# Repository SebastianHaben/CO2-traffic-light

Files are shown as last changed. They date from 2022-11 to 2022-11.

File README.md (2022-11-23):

## CO2 Traffic Light
The CO2 traffic light can help you to know when it is time to let some fresh air into your room and is also capable of logging your data online. The integrated CO2 & VOC (Volatile Organic Compounds) sensor tracks the air quality and indicates via an LED status light if the room air quality is good (green), ok(yellow) or bad (red) as well as display the values, as well as the room temperature on an e-Paper display.

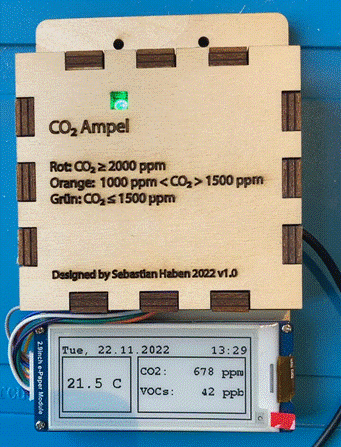
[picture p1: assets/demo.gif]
GIF of working project
  
  
### Contents
- Features
- Required parts
- Circuit & breadboard diagram
- Code and how to create a Firebase account
- Setting the correct timezone
- First start-up
- Laser cut housing
---
### Features
-	Measuring of temperature, eCO2 and VOC concentration in room air
-	Display of data as well as time and date (incl. correct time zone and daylight-saving time) on an e-Paper display.
-	Upload Data to a Google Firebase Realtime Database for analysis of historic trends
---
### Required parts
-	Wemos LOLIN D1 mini
-	Adafruit CSS811 air quality sensor
-	Adafruit MPL3115A2 Barometric Pressure Sensor
-	Waveshare 2.9 in E-Ink (E-Paper) display (black and white). Important: While other displays  sizes are also possible a lot of code rework (especially for graphics) will be necessary, for which no guide will be provided!
-	Adafruit Neopixel (or other WS2812B based  LED) or APA106 LED
-	Perf-board (I used a 40 x 60 mm one)

For Prototyping:
-	Large Breadboard
-	Dupont Jumper cables

For Housing:
-	6mm MDF plate
-	Screws (M2x8mm for Display and 2x10 mm for rest)
-	Hot glue or screws
---
### Circuit & Breadboard Diagram

The connections are done according to the breadboard view. In addition, a small table for each component is provided for each component with the corresponding pin on the D1 mini. 

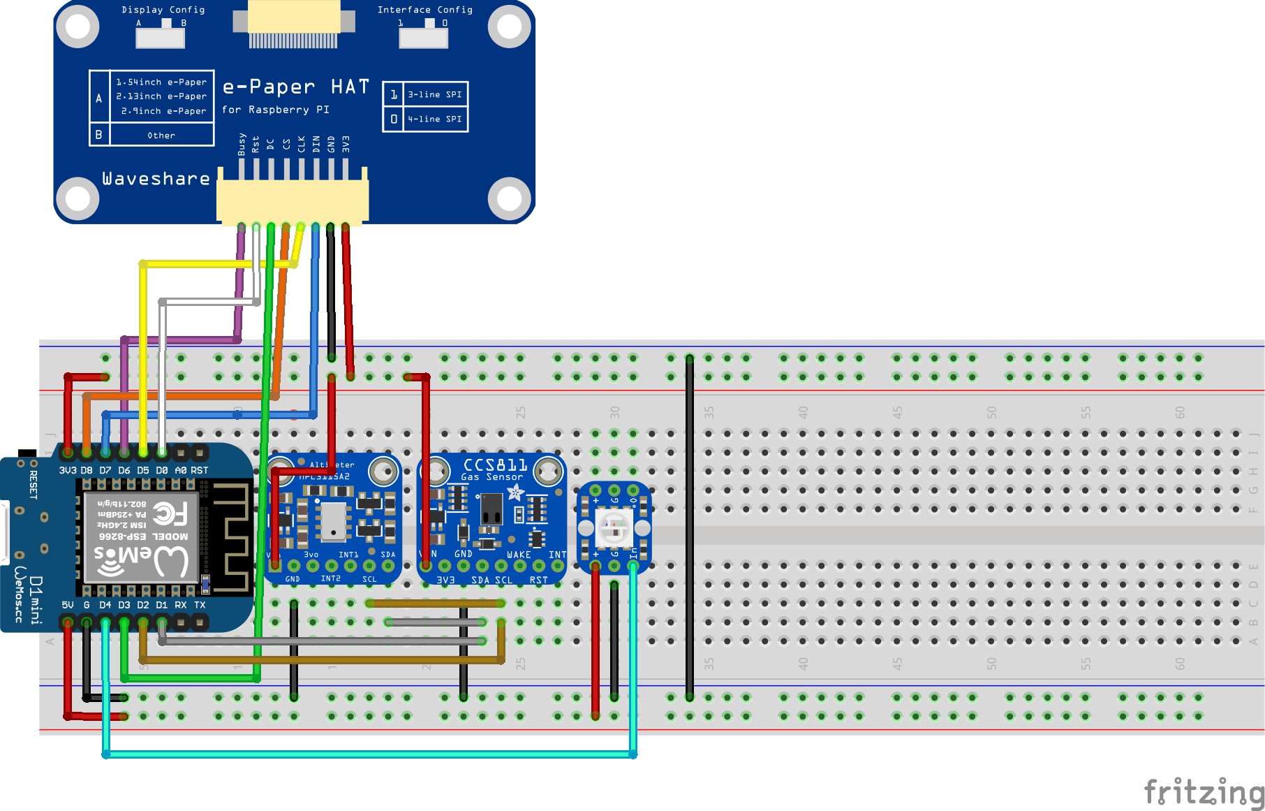
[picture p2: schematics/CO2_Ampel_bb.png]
Breadboard based hook-up diagram of project
  

__CSS811 & MPL3115A2__
|Pin on CSS811/MPL3115A2|Pin on D1 mini|
|:---:|:---:|
|VIN|3.3 V|
|GND|GND|
|SDA|D1|
|SCL|D2|

__Waveshare E-Ink Display__
|Pin on Waveshare|E-Ink Display	Pin on D1 mini|
|:---:|:---:|
|VCC|3.3 V|
|GND|GND|
|DIN|D7|
|CLK|D5|
|CS|D8|
|DC|D3|
|RST|D0|
|BUSY|D6|

__Neopixel__
|Pin on Neopixel|Pin on D1 mini|
|:---:|:---:|
|VIN|5V|
|GND|GND|
|DIN|D4|
---
### Code set-up and how to create a Firebase account
To run the project several things, need to be changed before flashing the code to the D1 mini. To save our data in the Google Firebase Realtime Database we first need to create a project in Google Firebase, create a new Realtime Database, grab the API-Key of the project and the database-URL as well as create the authentication via an e-mail address/ pass word combination. This handy tutorial will help you through each step of [setting up everything on Firebase.](https://randomnerdtutorials.com/esp8266-data-logging-firebase-realtime-database/)
After you have gathered all the required information you need to update the firebase-credentials.h file.

---
### Setting the correct time zone
To have the correct date and time displayed we need to set the correct time zone. This is done in line 84. To choose your correct time zone find your region and city in [this table](https://github.com/nayarsystems/posix_tz_db/blob/master/zones.csv) and replace the String with the corresponding string for your location.

---

### First start-up
After you have adjusted the code and the credentials you can flash it on the D1 mini. The final step is to connect the D1 mini to your WiFi. For this connect with your smartphone or tablet to the network “AutoConnectAP” and on the resulting page (if not forwarded automatically type 192.168.4.1 into your browser) find your WiFi’s SSID from the list and enter your password. The D1 mini should restart automatically and will connect to the WiFi. The credentials are stored on the D1 mini and are still available after a loss of power.

---

### Laser-cut Housing
I built this enclosure from 6mm birch MDF which might be also the new home for your own CO2 traffic light. I personally don’t own a laser cutter but online you can find shops that will cut the pieces for you at competitive rates. To place the project into the housing I soldered the sensors and the D1 mini onto a small perfboard.

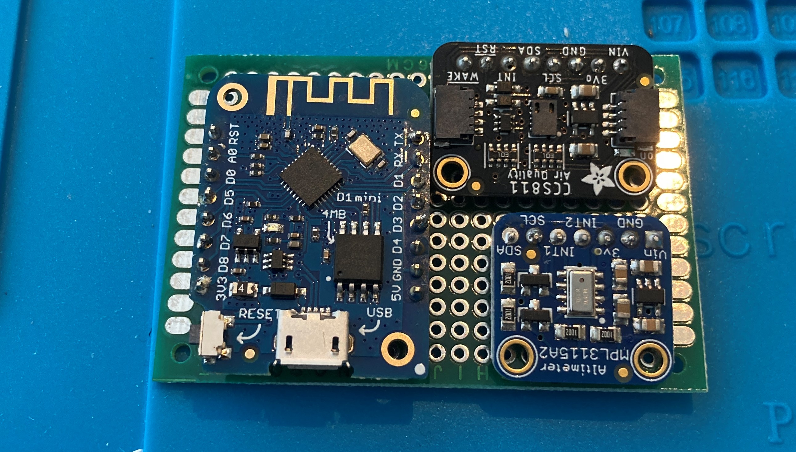
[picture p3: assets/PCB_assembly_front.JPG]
Front view PCB assembly
  
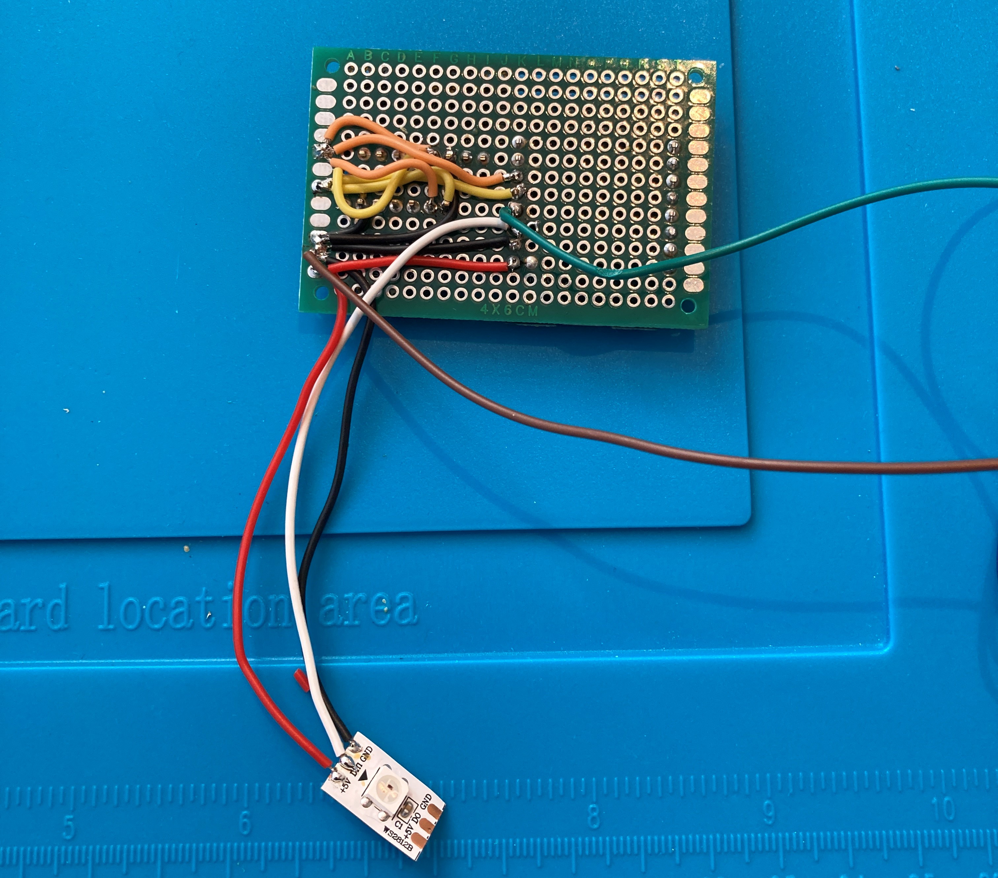
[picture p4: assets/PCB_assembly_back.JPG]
Back view PCB assembly
  
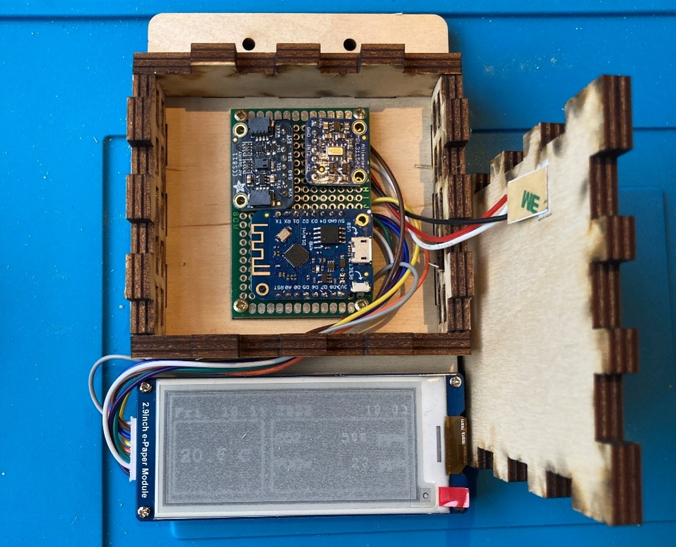
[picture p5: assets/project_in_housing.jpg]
Project in Housing


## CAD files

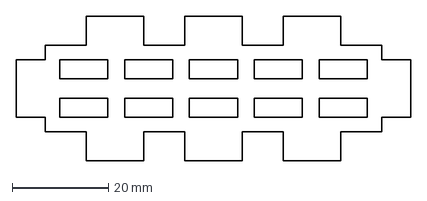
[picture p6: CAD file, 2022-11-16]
lasercutter housing/side.dxf
82.0 x 30.0 mm

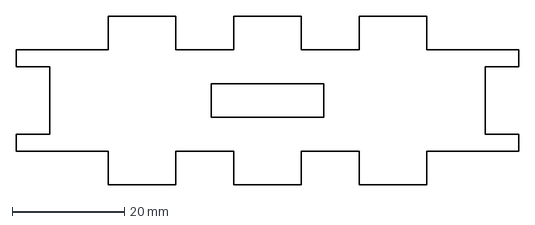
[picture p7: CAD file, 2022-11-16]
lasercutter housing/bottom.dxf
89.5 x 30.0 mm

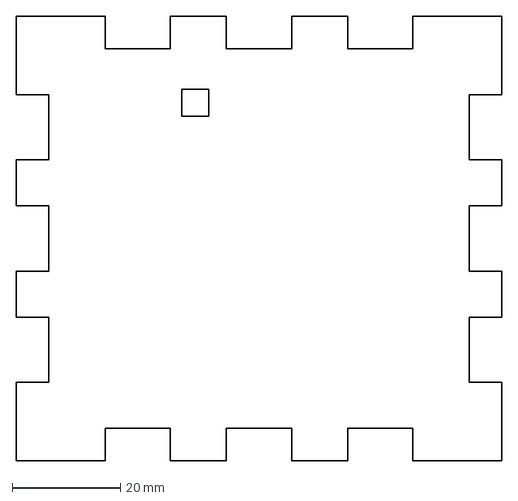
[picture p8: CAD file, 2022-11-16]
lasercutter housing/front.dxf
89.5 x 82.0 mm

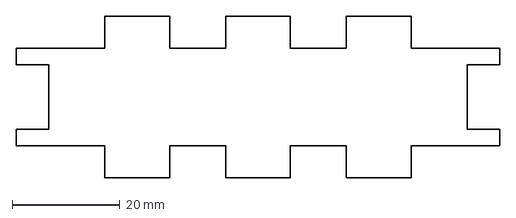
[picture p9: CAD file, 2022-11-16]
lasercutter housing/top.dxf
89.5 x 30.0 mm

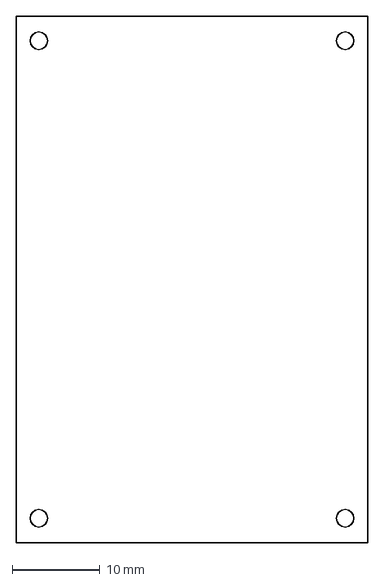
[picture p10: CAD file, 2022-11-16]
lasercutter housing/back_engra.dxf
40.0 x 60.0 mm

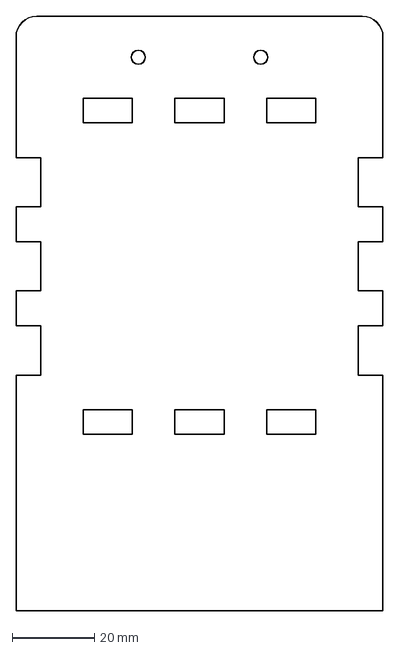
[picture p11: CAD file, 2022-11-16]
lasercutter housing/back.dxf
89.5 x 145.0 mm

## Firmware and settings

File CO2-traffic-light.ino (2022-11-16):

#include "time.h"
#include <Adafruit_NeoPixel.h>
#include <Wire.h>
#include <WiFiManager.h>
#include <Firebase_ESP_Client.h>
#include "addons/TokenHelper.h"
#include "addons/RTDBHelper.h"
#include <GxEPD2_BW.h>
#include "GxEPD2_display_selection_new_style.h"
#include <Fonts/FreeMonoBold9pt7b.h>
#include <Fonts/FreeMonoBold12pt7b.h>
#include "ccs811.h"
#include <Adafruit_MPL3115A2.h>
#include "firebase_credentials.h"

// Display information
#define SCREEN_WIDTH   296
#define SCREEN_HEIGHT  128
#define ENABLE_GxEPD2_GFX 0
// Static text on display
const char CO2[] = "CO2:";
const char VOCs[] = "VOCs:";

// Neopixel Information
#define NEOPIN  D4
#define NUMPIXELS 1

// DateTime information
struct tm lt;         
struct tm utc;
const char* ntpServer = "europe.pool.ntp.org";
struct tm timeinfo;

// Timer variables (send new readings every three minutes)
unsigned long sendDataPrevMillis = 0;
unsigned long timerDelay = 180000;

// Necessary for Firebase authentication
FirebaseData fbdo;
FirebaseAuth auth;
FirebaseConfig config;
FirebaseJson json;
String parentPath;
String uid;
String databasePath;
String tempPath = "/temperature";
String co2Path = "/eCO2";
String vocPath = "/VOC";
String timePath = "/timestamp";
String timeStamp;

// Initialize Neopixel & Sensors
Adafruit_NeoPixel pixels(NUMPIXELS, NEOPIN, NEO_GRB + NEO_KHZ800);
CCS811 ccs811(D3);
Adafruit_MPL3115A2 baro;

void setup() {
  Serial.begin(19200);
  // Use WifiManager to setup WiFi without providing password
  WiFiManager wm;
  bool res;
  res = wm.autoConnect("AutoConnectAP"); // password protected ap

    if(!res) {
        Serial.println("Failed to connect");
        // ESP.restart();
    } 
    else {
        //if you get here you have connected to the WiFi    
        Serial.println("connected...yeey :)");
    }
  // Start 
  Wire.begin(); 
  ccs811.set_i2cdelay(50); // Needed for ESP8266 because it doesn't handle I2C clock stretch correctly
  bool ok= ccs811.begin();
  if( !ok ) Serial.println("setup: CCS811 begin FAILED");
  ok= ccs811.start(CCS811_MODE_1SEC);
  if( !ok ) Serial.println("setup: CCS811 start FAILED");
  if (!baro.begin()) {
    Serial.println("Could not find sensor. Check wiring.");
    while(1);
  }
  // Get config time based on NTP server
  configTime("CET-1CEST,M3.5.0,M10.5.0/3", ntpServer);
  // Setup Display
  display.init();
  display_setup();
  display.hibernate();
  // Start-up Neopixel
  pixels.begin();
  pixels.setPixelColor(0, pixels.Color(32, 32, 32));
  // Connect to Firebase
  config.api_key = API_KEY;
  auth.user.email = USER_EMAIL;
  auth.user.password = USER_PASSWORD;
  config.database_url = DATABASE_URL;
  Firebase.reconnectWiFi(true);
  fbdo.setResponseSize(4096);
  // Feedback for token
  config.token_status_callback = FirestoreTokenStatusCallback;
  config.max_token_generation_retry = 5;
  // Initialize the library with the Firebase authen and config
  Firebase.begin(&config, &auth);
  // Getting the user UID might take a few seconds
  Serial.println("Getting User UID");
  while ((auth.token.uid) == "") {
    Serial.print('.');
    delay(1000);
  }
  uid = auth.token.uid.c_str();
  Serial.print("User UID: ");
  Serial.println(uid);
  // Update database path
  databasePath = "/UsersData/" + uid + "/CO2Ampel/readings";
}

void loop() {
  // Initiallize variables for readings
  uint16_t eco2, etvoc, errstat, raw;
  float temperature;
  
  // Get temperature
  temperature = baro.getTemperature();
  // Parse temperature & humidity to ccs811. Standrad value of 40% relative humidity is used due to lack of humidity sensor. 
  ccs811.set_envdata_Celsius_percRH(temperature, 40.0);
  ccs811.read(&eco2,&etvoc,&errstat,&raw);
  // Set color of Neopixel based on current CO2 value.
  if (eco2 <= 1000){
        pixels.setPixelColor(0, pixels.Color(0, 20, 0));
        }
      else if (eco2 > 1000 && eco2 <= 2000){
        pixels.setPixelColor(0, pixels.Color(10, 10, 0));
        }
      else{
        pixels.setPixelColor(0, pixels.Color(20, 0, 0));
        }
  pixels.show();
  // Update display
  if(!getLocalTime(&timeinfo,500)){
    Serial.println("Failed to obtain time");
    return;
  }
  time_t now = time(&now);
  localtime_r(&now, &lt);
  gmtime_r(&now, &utc);
  updateDate(timeinfo);
  updateAirQuality(eco2, etvoc);
  updateEnvironment(temperature);
  if (Firebase.ready() && (millis() - sendDataPrevMillis > timerDelay || sendDataPrevMillis == 0)){
    sendDataPrevMillis = millis();
    static char buf[30];
    strftime (buf, sizeof(buf), "%d.%m.%Y %T", &utc); 
    timeStamp= String(buf);

    parentPath= databasePath + "/" + timeStamp;

    json.set(tempPath.c_str(), String(temperature));
    json.set(co2Path.c_str(), String(eco2));
    json.set(vocPath.c_str(), String(etvoc));
    json.set(timePath, timeStamp);
    Serial.printf("Set json... %s\n", Firebase.RTDB.setJSON(&fbdo, parentPath.c_str(), &json) ? "ok" : fbdo.errorReason().c_str());
  }
  if (!(time(&now) % 86400)) {                          // einmal am Tag die Zeit vom NTP Server holen o. jede Stunde "% 3600" aller zwei "% 7200"
    configTime("CET-1CEST,M3.5.0,M10.5.0/3", ntpServer);  
    }
  delay(1000);
}

//Initialize all static elements of the display
void display_setup()
{
  display.setRotation(1);
  display.setFont(&FreeMonoBold9pt7b);
  display.setTextColor(GxEPD_BLACK);
  display.setFullWindow();
  display.firstPage();
  do
  {
    display.drawRect(3,3,292,124,GxEPD_BLACK);
    display.drawRect(4,4,290,122,GxEPD_BLACK);
    display.drawRect(8,33,106,85,GxEPD_BLACK);
    display.drawRect(9,34,104,83,GxEPD_BLACK);
    display.drawRect(123,33,164,85,GxEPD_BLACK);
    display.drawRect(124,34,162,83,GxEPD_BLACK);
  display.setCursor(127, 60);
  display.print(CO2);
  display.setCursor(127, 90);
  display.print(VOCs);
  }
  while (display.nextPage());
}

// Update date and time information on display
void updateDate(struct tm timeinfo)
{ 
  display.setFont(&FreeMonoBold9pt7b);
  display.setTextColor(GxEPD_BLACK);
  String date;
  char timeHour[3];
  strftime(timeHour,3, "%H", &timeinfo);
  char timeMinute[3];
  strftime(timeMinute,3, "%M", &timeinfo);
  char dateWeekDay[4];
  strftime(dateWeekDay,4, "%a", &timeinfo);
  char dateDay[3];
  strftime(dateDay,3, "%d", &timeinfo);
  char dateMonth[3];
  strftime(dateMonth,3, "%m", &timeinfo);
  char dateYear[5];
  strftime(dateYear,5, "%Y", &timeinfo);
  date= String(dateWeekDay)+", "+String(dateDay)+"."+String(dateMonth)+"."+String(dateYear);
  String t;
  t = String(timeHour)+":"+String(timeMinute);
  int16_t dbx, dby; uint16_t dbw, dbh;
  int16_t tbx, tby; uint16_t tbw, tbh;
  display.getTextBounds(date, 0, 0, &dbx, &dby, &dbw, &dbh);
  display.getTextBounds(t, 0, 0, &tbx, &tby, &tbw, &tbh);
  display.setPartialWindow(8,8, display.width()- 2*8, FreeMonoBold9pt7b.yAdvance);
  display.firstPage();
  do
  {
  display.setCursor(8,8+FreeMonoBold9pt7b.yAdvance/2-dby);
  display.print(date);
  display.setCursor(display.width()- 8 - tbw - tbx,8+FreeMonoBold9pt7b.yAdvance/2-tby);
  display.print(t);
  }
  while(display.nextPage()); 
}

// Update air quality variables on display
void updateAirQuality(uint16_t eco2, uint16_t etvoc)
{
  display.setFont(&FreeMonoBold9pt7b);
  display.setTextColor(GxEPD_BLACK);
  String eco2String = String(eco2) + " ppm";
  String etvocString = String(etvoc) + " ppb";
  int16_t co2bx, co2by; uint16_t co2bw, co2bh;
  int16_t vocbx, vocby; uint16_t vocbw, vocbh;
  display.getTextBounds(eco2String, 0, 0, &co2bx, &co2by, &co2bw, &co2bh);
  display.getTextBounds(etvocString, 0, 0, &vocbx, &vocby, &vocbw, &vocbh);
  int boxw = 156;
  display.setPartialWindow(127+boxw/3,40, (boxw/3)*2, 70);
  display.firstPage();
  do
  {
    display.setCursor(display.width()- 12 - co2bw - co2bx,60);
    display.print(eco2String);
    display.setCursor(display.width()- 12 - vocbw - vocbx,90);
    display.print(etvocString);
  }
  while(display.nextPage()); 
}

// Update temperature on display
void updateEnvironment(float temperature)
{
  display.setFont(&FreeMonoBold12pt7b);
  display.setTextColor(GxEPD_BLACK);
  String tString = String(temperature,1) + " C";
  int16_t tbx, tby; uint16_t tbw, tbh;
  display.getTextBounds(tString, 0, 0, &tbx, &tby, &tbw, &tbh);
  int boxw = 98;
  display.setPartialWindow(12,40, boxw , 70);
  display.firstPage();
  do
  {
    display.setCursor(15,80);
    display.print(tString);
  }
  while(display.nextPage());
}


void FirestoreTokenStatusCallback(TokenInfo info){
  Serial.printf("Token Info: type = %s, status = %s\n", getTokenType(info), getTokenStatus(info));
}

bool getLocalTime(struct tm * info, uint32_t ms)
{
    uint32_t start = millis();
    time_t now;
    while((millis()-start) <= ms) {
        time(&now);
        localtime_r(&now, info);
        if(info->tm_year > (2016 - 1900)){
            return true;
        }
        delay(10);
    }
    return false;
}
  
